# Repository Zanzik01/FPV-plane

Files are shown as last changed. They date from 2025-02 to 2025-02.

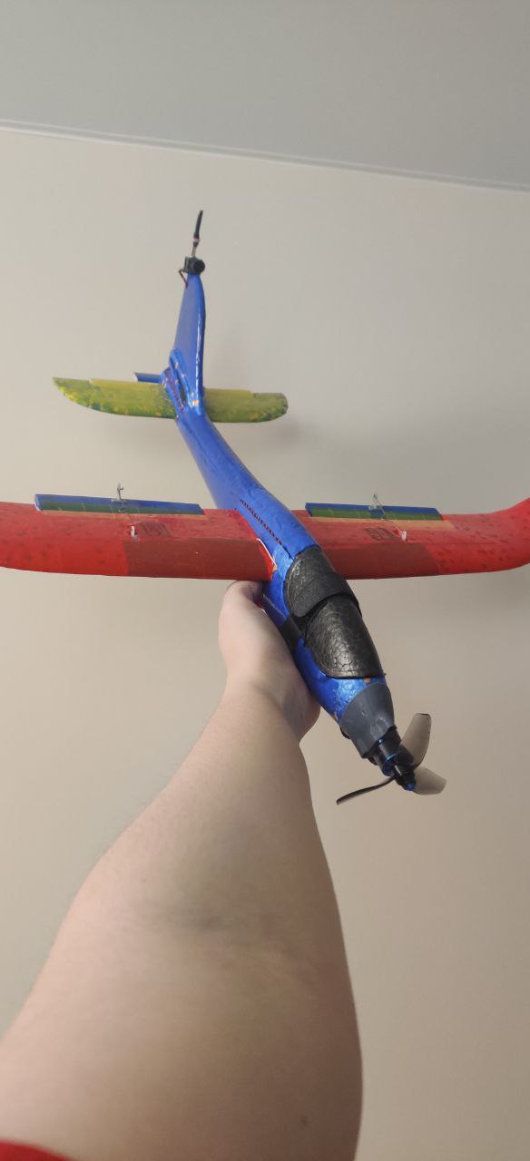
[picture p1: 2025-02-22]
images/FPV aircraft.jpg

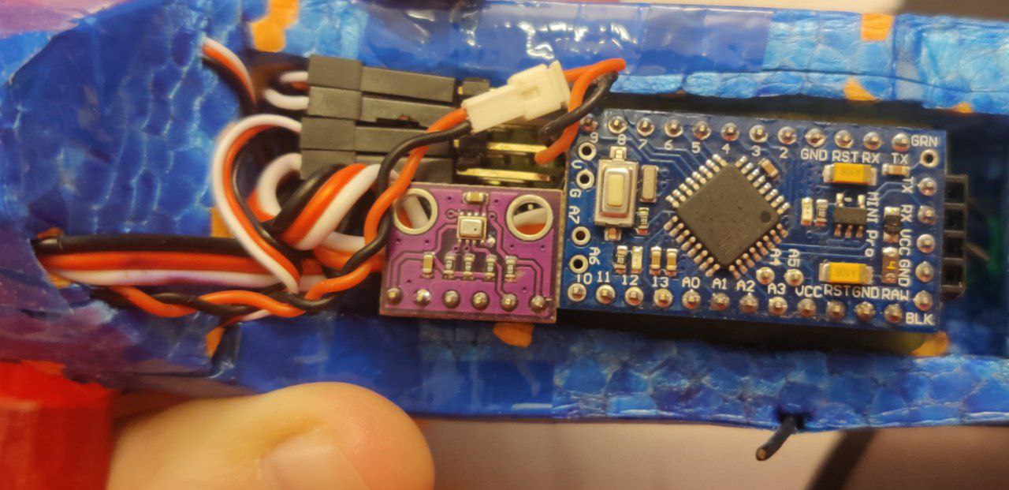
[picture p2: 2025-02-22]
images/The control device.jpg

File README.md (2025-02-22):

# FPV самолет

Это небольшой проект по созданию FPV самолета. За основу был взят небольшой планер из EPP, коих много в детских магазинах с игрушками. Описывать установку невесного оборудования подробно не буду, так как этой информации много в интернете. Расскажу только про ВМГ и ПО.

## ВМГ

В качестве винто-моторной группы был выбран самый простой и очевидный вариант. Один бесколлекторный мотор 1408 3800KV с 5мм валом для пропеллера. Так как размах крыла всего 48см устанавливать что-то более мощное мне показалось бессмысленным. EPP материал достаточно мягкий и рыхлый, что исключает монтаж мотора напрямую в него. Тянущая сила винта попросту вырвет его. Поэтому в Fusion 360 мною была смоделирована деталь, которая повторяет контуры носа самолета. Также она имеет 4 сквозных отверстия, они необходимы для улучшения фиксации детали на носу самолета. В эти отверстия мною были вставлены и вклеены части зубочисток, после чего вся деталь клеилась на нос самолета. Также в эту деталь с помощью паяльника были установлены закладные гайки М2.5х5.

Motor mount part 2
Скриншот второй части крепления мотора

Другая деталь нужна для непосредственного крепления мотора. Сначала винтами М2 из комплекта поставки мотора крепим его к детали, а потом всю эту конструкцию винтами М2.5х8 крепим к устанновленному ранее основанию к самолету.

Motor mount part 1
Скриншот первой части крепления мотора

Motor mount
Скриншот крепления для мотора

## Программа

Полетный контроллер сюда ставить не отелось в силу размеров. Приёмника с PWM пинами у меня также не было под рукой, поэтому было принято решение реализовать всё на платформе Arduino. Для этого как мне изначально показалось идеально подойдет Arduino Mini Pro, так как чип на котором она работает это тот же чип, что и в Arduino Nano и Arduino Uno, а значит программно работа не поменяется. Вариант с Arduino Nano кажется более логичным... И да это так, поэтому если соберетесь повторять, то используете лучше Arduino Nano. Возня с программатором при каждой перепрошивкей меня не пугала в начале, поэтому у меня используется Arduino Mini Pro в силу её меньших размеров. Касаемо остальных компонентов, тут всё просто. Для приёма управляющих сигналов и передачи телеметрии был использован ELRS приёмник 2.4 ГГц разницы между производителями особо нет, поэтому вы можете использовать любой. Для управления мотором используется регулятор оборотов для бесколлекторного двигателя расчитанный на 20А (ESC). Для управления достаточно простого PWM сигнала поэтому в коде это было реализовано через объект класса Servo. Для управления элеронами и рулем высоты используются самые маленькие сервоприводы, которые мне удалось найти в продаже. Также мною был установлен барометр, с помощью которого измерялась высота и отправлялась в пакете телеметрии на пульт. Также был сделан делитель напряжения с помощью двух реззисторов для измерения напряжения на аккумуляторе. Этот параметр также отправлялся на пульт, чтобы следить за состоянием аккумулятора и не уводить его в глубокий разряд. Заморочки с телеметрией и отправкой её на пульт были нужны так как на самолете установлена самая дешевая FPV камера 3 в 1, которая не имеет возможности наложения OSD, но у неё есть и плюс для её работы необходимо просто кодать питание 5В.

FPV aircraft

Вот что у меня получилось в итоге)

The control device
Для тех кому интересно заглянуть внутрь)

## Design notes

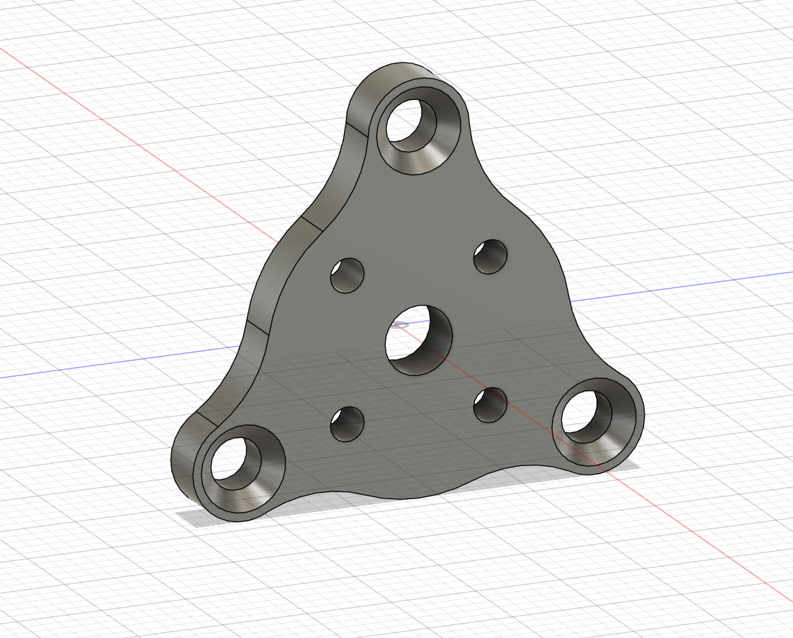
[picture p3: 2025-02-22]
images/Motor mount part 1.jpg

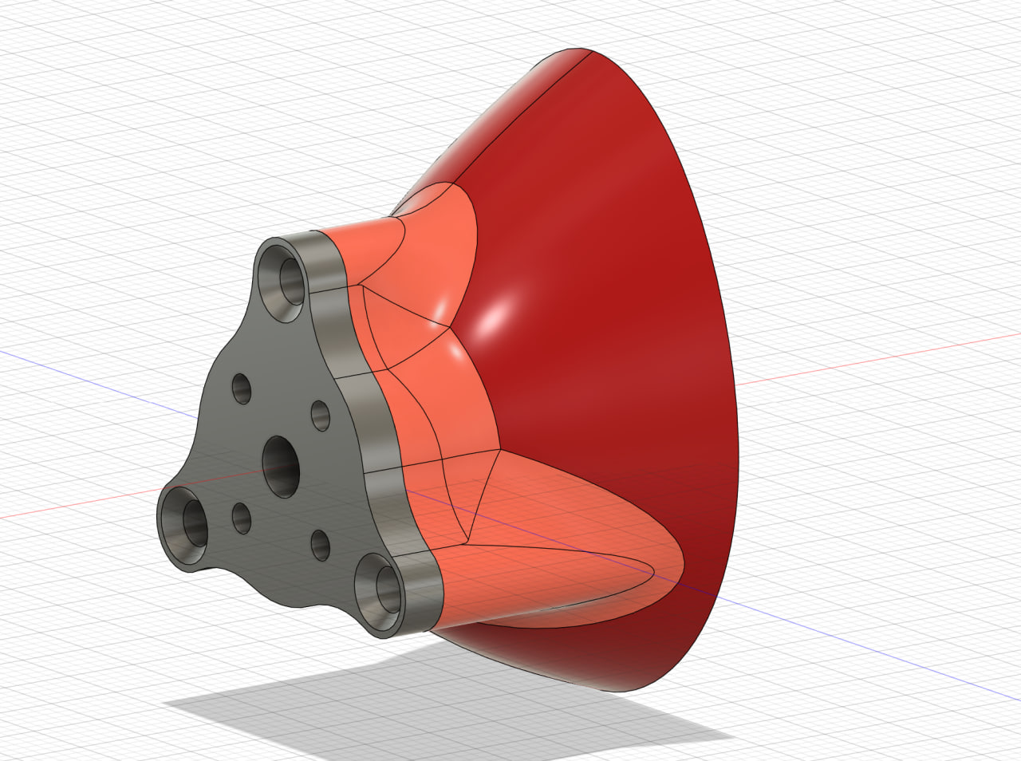
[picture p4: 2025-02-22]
images/Motor mount.jpg

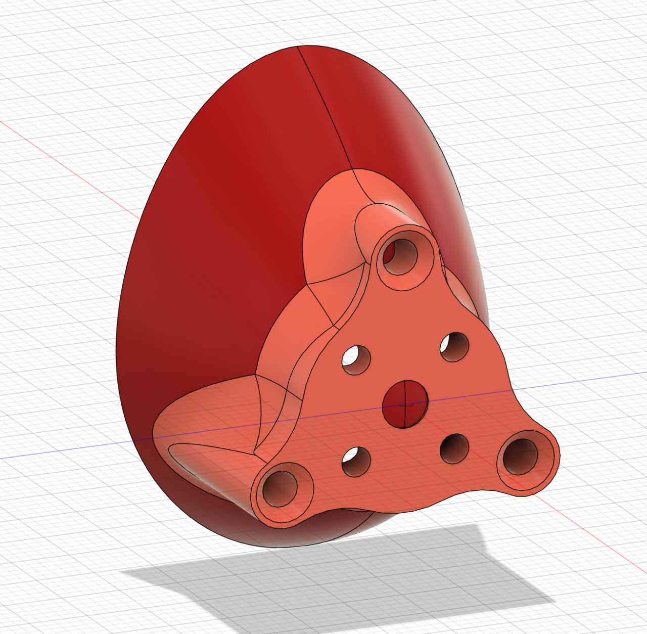
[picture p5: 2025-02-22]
images/Motor mount part 2.jpg

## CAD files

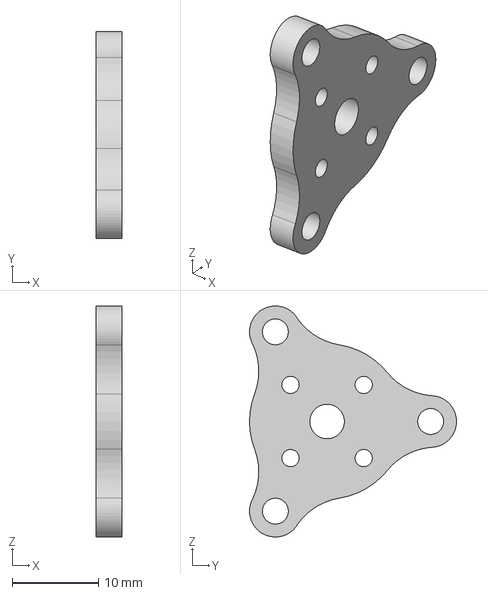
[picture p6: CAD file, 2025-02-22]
models/STEP/Motor mount part 1.step
3.00 x 24.0 x 26.8 mm

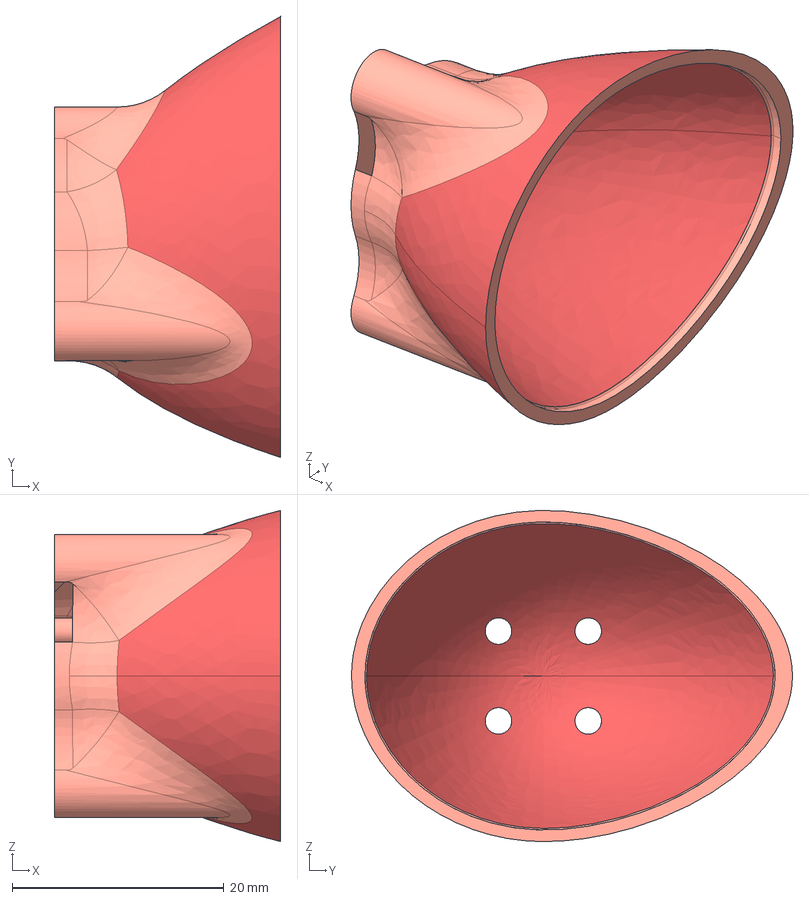
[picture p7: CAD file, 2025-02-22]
models/STEP/Motor mount part 2.step
21.4 x 41.7 x 31.3 mm

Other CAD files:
models/STL/Motor mount part 1.stl
models/STL/Motor mount part 2.stl

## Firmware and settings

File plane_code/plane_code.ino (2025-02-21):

#include "CrsfSerial.h"
#include <Servo.h>
#include <Adafruit_BMP280.h>

#define PIN_VOLTAGE_SENSOR        A0
#define PIN_SERVO_ELEVATOR         3
#define PIN_SERVO_LEFT_AILERON     5
#define PIN_SERVO_RIGHT_AILERON    10
#define PIN_GAS                    9
#define PIN_BUZZER                6

Servo Servo_left_aileron;
Servo Servo_right_aileron;
Servo Servo_elevator;
Servo ESC;

Adafruit_BMP280 bmp;

int notes[] = {
  392, 392, 392, 311, 466, 392, 311, 466, 392,
  587, 587, 587, 622, 466, 369, 311, 466, 392,
  784, 392, 392, 784, 739, 698, 659, 622, 659,
  415, 554, 523, 493, 466, 440, 466,
  311, 369, 311, 466, 392,
};

int times[] = {
  350, 350, 350, 250, 100, 350, 250, 100, 700,
  350, 350, 350, 250, 100, 350, 250, 100, 700,
  350, 250, 100, 350, 250, 100, 100, 100, 450,
  150, 350, 250, 100, 100, 100, 450,
  150, 350, 250, 100, 750,
};

typedef struct remoteData_s {
  uint16_t voltage;
} remoteData_t;

remoteData_t remoteData;

float adc_voltage = 0.0;
float in_voltage = 0.0;
 
float R1 = 30000.0;
float R2 = 7500.0; 
 
// Значение опорного напряжения
float ref_voltage = 5.0;

int adc_value = 0;

float expRunningAverageAdaptive(float newVal) {
  static float filVal = 0;
  float k;
  // резкость фильтра зависит от модуля разности значений
  if (abs(newVal - filVal) > 1.5) k = 0.9;
  else k = 0.03;
  
  filVal += (newVal - filVal) * k;
  return filVal;
}

CrsfSerial crsf(Serial, 500000);

static void crsfLinkUp() {
  digitalWrite(LED_BUILTIN, HIGH);
}

static void crsfLinkDown() {
  digitalWrite(LED_BUILTIN, LOW);
 }

int ch1 = 1500;
int ch2 = 1500;
int ch3 = 1500;
int ch4 = 1500;
int ch5 = 1500;
int ch6 = 1500;
int ch7 = 1500;
int ch8 = 1500;
int ch9 = 1500;
int ch10 = 1500;

void setup() {
  Serial.begin(500000);
  crsf.onLinkUp = &crsfLinkUp;
  crsf.onLinkDown = &crsfLinkDown;

  for (int i = 0; i < 39; i++) {
    tone(PIN_BUZZER, notes[i], times[i]*2);
    delay(times[i]*2);
    noTone(PIN_BUZZER);
  }

  if (!bmp.begin()) {  
    Serial.println(F("Could not find a valid BMP280 sensor, check wiring!"));
    while(1);
  }

  Servo_left_aileron.attach(PIN_SERVO_LEFT_AILERON);
  Servo_right_aileron.attach(PIN_SERVO_RIGHT_AILERON);
  Servo_elevator.attach(PIN_SERVO_ELEVATOR);
  ESC.attach(PIN_GAS);

}

void loop() {
  crsf.loop();
  // руль высоты
  ch2 = map(crsf.getChannel(2),2000,1000,55,125);
  Servo_elevator.write(ch2);
  // Элероны
  ch4 = map(crsf.getChannel(4),2000,1000,55,125);
  Servo_left_aileron.write(ch4);
  Servo_right_aileron.write(ch4);

  // Арм
  if (crsf.getChannel(5) == 2000){
    // газ
    ch3 = map(crsf.getChannel(3),2000,1000,55,125);
    ESC.write(ch3);
    // Serial.println("АРМ");
    } else {
      ESC.write(1000);
      // Serial.println("Дизарм");
      }
  // Протокол "Потеряшка"
  if (crsf.getChannel(6) == 2000){
    tone(PIN_BUZZER, 1000); //пищалка орет
  }else{
      noTone(PIN_BUZZER);//пищалка не орет
      }
  // Протокол "высота"
  if (crsf.getChannel(7) == 1000){
    // Вывод данных с барометра в монитор порта для теста
    // Serial.print(F("Temperature = "));
    // Serial.print(bmp.readTemperature());
    // Serial.println(" *C");
    
    // Serial.print(F("Pressure = "));
    // Serial.print(bmp.readPressure());
    // Serial.println(" Pa");
 
    // Serial.print(F("Approx altitude = "));
    Serial.print(bmp.readAltitude(1012.23)); //переменная подстраивается под высоту местности
    // Serial2.print(bmp.readAltitude(1012.23));
    // Serial.println(" m");
  }
  // Протокол "напряжение"
  if (crsf.getChannel(8) == 1000){
    // ВЫВОД ДАННЫХ НАПРЯЖЕНИЯ БАТАРЕИ
    adc_value = analogRead(PIN_VOLTAGE_SENSOR);
   
    adc_voltage  = (adc_value * ref_voltage) / 1024.0; 
   
    in_voltage = adc_voltage / (R2/(R1+R2)) ; 
   
    //Serial.print("Input Voltage = ");
    Serial.println(in_voltage, 2);
  }
}
